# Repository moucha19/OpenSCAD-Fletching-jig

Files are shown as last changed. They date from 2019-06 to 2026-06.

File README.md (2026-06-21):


# OpenSCAD Fletching jig

## Overview
Simple yet effective fletching jig that will adjust to all your needs. Intended to provide new archers with access to 3D printer cheap way to fix broken arrows without a need for expensive off-the-shelf jig. Hopefully, even skilled shooters may find utility in this design.

### Features

+ highly adjustable to fit different arrows and vanes
+ supports any number of vanes (typically 3 or 4)
+ straight, offset and **true** helical fletchings
+ features optional nock alignment
+ no additional tools required for assembly
+ hot swappable arms
+ very compact and light 

## Prerequisites

First you have to download latest version (2019.05 or newer) of [OpenSCAD](http://www.openscad.org/downloads.html). It's free and open source software available for all major desktop platforms. Nothing else is needed for editing and rendering. 

Additional software required will vary depending on your 3D printer.

## How to use

Although I provide several pre-rendered files as an example, it is very likely that you will not like something about them. If some of the parameters do not fit your setup or you simply want to enable some special features mentioned above, you will have to change the relevant parameters in the OpenSCAD customizer and render a new, unique jig yourself. Don't worry though, it is very simple!

1. Download and extract [latest release](https://github.com/moucha19/OpenSCAD-Fletching-jig/releases) of this project somewhere on your PC.
2. Locate [main.scad](./scad/main.scad) and open it in OpenSCAD. 
3. Go to the **Customizer** section:
   - **Windows/Linux**: Click on `Window` in the top menu and select `Customizer`.
   - **macOS**: Click on `View` in the top menu, then select `Customizer`.
4. The Customizer panel will appear on the right side of the OpenSCAD interface.
   - If you don't need to see or edit the code, you can close the editor window on the left to focus solely on the Customizer and 3D view.
5. Adjust the parameters:
   - You will see a list of customizable parameters, such as dimensions and features. See the table below for the detailed description or refer to [parameter reference drawing](./doc/parameter-reference.pdf).
   - Modify these parameters as needed to customize your model.
   - I did all i could to prevent user from inserting invalid values, but there could still be ways to generate completely invalid design - so be reasonable. I'd advise you to change parameters you're sure about first (arrow_diameter, vane_length etc.) and then adjust the rest.
6. **Preview your changes** in real-time. The 3D model will update automatically as you adjust the parameters.
7. Once you're satisfied with the customization, you can render the model (`F6`) and export it to your desired format with `File > Export > ...`.
   - By default, you will get file with every jig part. However, by changing `part_select` parameter, you can isolate individual parts in their correct orientation for 3D printing. This way you can split the jig into multiple files.

### Parameters

Parameter | Description | Thresholds
--- | --- | ---
base_style | choose the base shape | `"polygon"` or `"star"`
lid_style | choose the outer lid shape | `"polygon"` or `"star"`
joint_style | either snap-in ball joints or pin joints | `"ball"` or `"pin"`
arrow_diameter | slightly bigger than the arrow itself (may vary depending on your printer) | 2 < ■
arrow_offset | distance between the bottom of the base and arrow | 0 < ■ < `base_height`
base_height | height of the base | 5 < ■
hinge_width | width of the hinge cutout on the base | 2.2 < ■ < *depends on arrow_diameter*
hinge_thickness | thickness of the hinge extension attached to the bottom of the arm | 1 < ■ < *depends on hinge_width and joint_diameter*
hinge_diameter | diameter of the circular part of the hinge that revolves around a joint | 2 < ■ < `hinge_depth`
hinge_depth | how deep into the base is the hinge cutout | 5 < ■ < `base_height`
joint_diameter | diameter of the joint that connects two halves of the hinge together | 0 < ■ < *depends on joint_style*
arm_gap | gap for the vane foot, so that tension during clamping is distributed evenly and the vane fits in the closed jig | 0 < ■ < 1.5
arm_offset | distance between the top of the base and bottom of the arm | 0 < ■
lid_gap | space between the lid and arms, higher values will produce looser fit (may vary depending on your printer)  | 0 < ■
vane_count | number of vanes, typically 3 or 4 | 2 < ■ 
vane_style | changes shape of the vane | `"straight"` or `"helical"`
vane_length | length of the vane | 0 < ■
vane_width | width of the vane | 0 < ■ < *in the console*
vane_offset | how far from the end of the arrow will the vane be | *in the console* < ■
vane_turn | sets rotation of the fletching in degrees, negative values flip the direction | ■ < *in the console*
nock | choose whether to add a nock alignment guide and if so, how you want to rotate it | `"none"`, `"reference"` or `"alternate"`
nock_width | width of the nock guide, smallest point of the arrow nock | 0 < `arrow_diameter`
nock_height | depth of nock in your arrow, this will be the height of the nock guide | 0 < `(base_height - arrow_offset)`
nock_diameter | if the nock alignment guide is enabled, this value takes precedence over `arrow_diameter` for the base hole when the nocked arrow is wider than bare shaft | 0 < ■



### Thresholds

Like I already mentioned, I've take some precautions to ensure a valid outputs.

First are constrained sliders in customizer. These are set to accommodate even extreme values and should be sufficient for everyone. They're nothing more than recommendations though and even values beyond their range may work just fine. If - for any reason - you'd want to allow values outside of default range, you can do so in `main.scad` by editing lines just like this one:

```openscad
//distance between the bottom of the base and arrow
arrow_offset = 3;//[0:0.1:100] 
```
where comment behind the assignment means *[min:precision:max]*. Go to [customizer documentation](https://customizer.makerbot.com/docs) for more information.

Second are thresholds in the module itself that are actually checking if desired parameters make sense or not. For example, if you have small jig for 6mm arrows, you can't have 10 centimeter wide hinge. So even if you're able to set something like this in the customizer, invalid parameters will be truncated in the module to a closest valid value. If this happens, you'll be informed about it in the console window with similar line:

> hinge_thickness threshold (max = 5.25) reached!

List of some thresholds is in the table above. Some extreme values may still produce invalid results. That could either be because fixing it is more trouble than it's worth or because calculation of thresholds is impossible. Or it can simply be an oversight on my part. If you think something can be improved or you discover a bug, raise an issue or submit PR. 

Also, not all parameters are available in the customizer. Some of them do not change and should not have an effect on the validity of the generated output. However, if you did some testing and think some of these default values could be adjusted to generate better results, let me know.

## Printing recommendations

These settings were tested on Prusa MK2S. You might need to adjust them slightly.

Part | Layer height | Infill | Supports | Bed placement
--- | --- | --- | --- | --- 
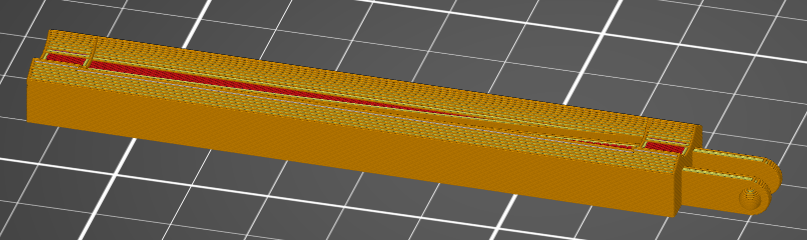
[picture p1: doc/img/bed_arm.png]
Arm | 0.15mm or better | 15% | none / 3mm brim | 
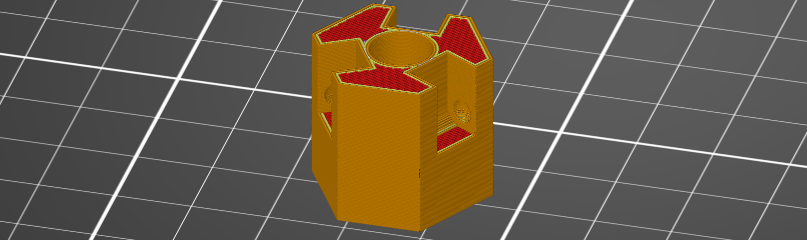
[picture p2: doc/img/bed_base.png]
Base | 0.2mm or better  | 15% | none | 
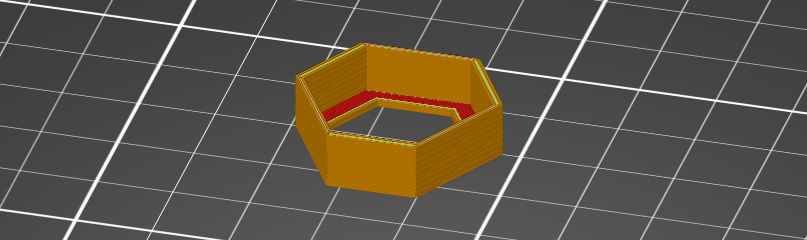
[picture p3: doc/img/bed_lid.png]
Lid | 0.35mm | solid | none | 

***

<br />This work is licensed under a <a rel="license" href="http://creativecommons.org/licenses/by-nc-sa/4.0/">Creative Commons Attribution-NonCommercial-ShareAlike 4.0 International License</a>.

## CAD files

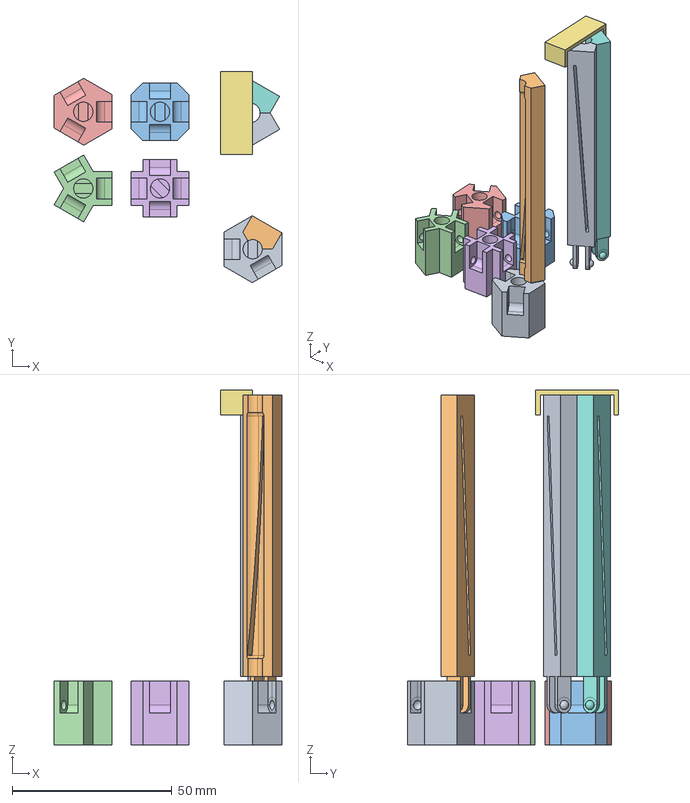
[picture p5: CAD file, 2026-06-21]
doc/parameter-reference.FCStd
71.3 x 66.1 x 111.1 mm
OffsetRotatedBaseBody
OffsetRotatedArmBody
Base4PolygonReferenceSolid
Base3StarAlternateSolid
Base3PolygonReferenceSolid
Base4StarAlternateSolid
LidBody
LidArmBodyLeft
LidArmBodyLeft001

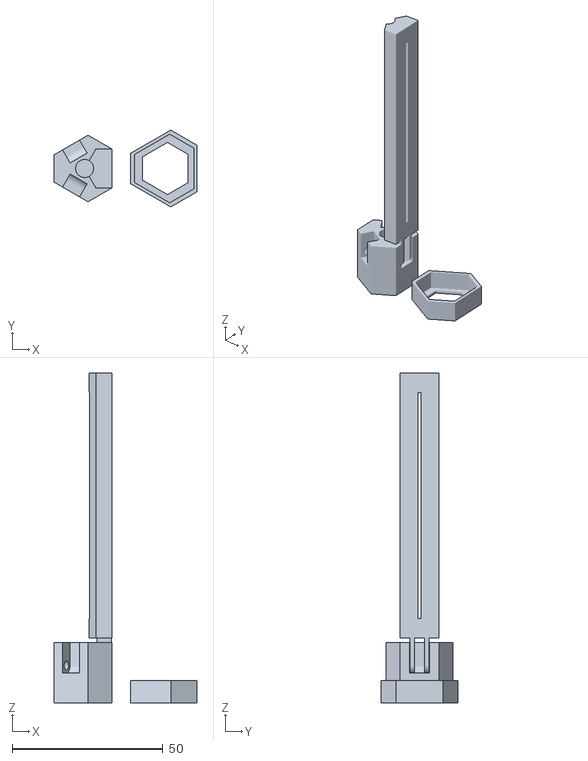
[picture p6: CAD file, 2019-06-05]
stl/jig_6.0_straight.stl
47.4 x 25.5 x 109.5

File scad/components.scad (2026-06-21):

use <MCAD/regular_shapes.scad>

//
//Check out following video made by Eric Buijs
//for more information about bezier curves
//https://www.youtube.com/watch?v=jVPJetq0BZg
//

module bezier (p0, p1, p2, w)
{
    deltat = 0.02;
    cline = [for (t=[0:deltat:1]) pow(1-t,2)*p0+2*(1-t)*t*p1+pow(t,2)*p2];
    last = len(cline) - 1;
    rline = [for(i = [0 : last]) [cline[i].x, cline[i].y - w/2]];
    lline_rev = [for(i = [len(cline) - 1 : -1 : 0]) [cline[i].x, cline[i].y + w/2]];
    //TODO Only works in one orientation
    translate([((p2.x-p0.x)-cline[last].x)/2, 0]) //corrects calculation error 
        polygon(concat(rline, lline_rev));
}

//
//Creates a fillet shape for difference operator
//# r - fillet radius
//# w - width of the filleted edge
//# center - centers on the circle 
//
module fillet(r = 5, w = 5, center=true)
{
    difference()
    {
        translate([r/2,r/2,0]) cube([r,r,w], center=center);
        cylinder(r=r, h=2*w+0.1, center=center);
    }
}

//
//Creates a fillet shape for difference from a cylinder
//# rc - radius of the cylinder
//# r1 - width radius of the fillet
//# r2 - height radius of the fillet 
//# bottom - if true, fillet is generated for the bottom edge, otherwise for the top edge
//

module cylinder_fillet(rc = 5, r1 = 1, r2 = 1, bottom = true)
{
    rotate_extrude(angle = 360, convexity = 2) 
    translate([rc,0,0]) difference()
    {
        square([r1,r2], false);
        translate(bottom ? [0,r2] : [0,0]) 
        ellipse(2*r1, 2*r2);
    }
}

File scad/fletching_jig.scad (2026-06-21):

use <components.scad>

//Functions that create console messages
module error_threshold (value_name, threshold_name, value, threshold)
{
    if (value == threshold) 
    {
        message = str(value_name," threshold (", threshold_name, " = ", threshold, ") reached!");
        if (version()[0] > 2019)
            echo(message);
        else
            echo(str("<font color='red'>", message, "</font>"));
    }
}
module info_threshold (value_name, threshold_name, threshold)
{
    message = str("Current ", threshold_name, " for ", value_name, " is ", threshold);
    if (version()[0] > 2019)
        echo(message);
    else
        echo(str("<font color='blue'>", message, "</font>"));
}

//
//Creates helical vane
//# width - width of the extruded vane profile
//# length - length of the vane
//# height - extrusion height
//# spread - horizontal distance between edges of the vane
//# twist - total twist angle applied across the extrusion
//# direction - sign of the value determines left or right spin (+ left; - right)
//
module helical_vane (width = 1, length = 75, height = 10, spread = 4, twist = 15, direction = 1)
{
    direction = sign(direction);
    length = length;
    rotate([0,90,0])
        linear_extrude(height, center = false, twist = -direction*twist, scale = 1)
            translate([-length/2,0,0])
                bezier([0,-direction*spread],[0.5*length,-direction*spread],[length,direction*spread],width);
}

//
//Creates basic shape of the jig's base
//# style - style of the outline
//# a - length of primary side
//# radius - distance from center to midpoint of primary side (apothem)
//# vane_count - number of vanes
//
module base_outline (style, a, radius, vane_count)
{
    rotation_by = 360/vane_count;
    or = sqrt(pow(a/2, 2) + pow(radius, 2)); //? outside radius
    alpha = atan((a/2)/radius); //? half angle of the hinge side
    beta = (rotation_by - 2*alpha)/2; //? half angle of the secondary side
    b = 2 * or * sin(beta); //? secondary side length
    cross_radius = (or * cos(beta)) - ((b/2)*tan((180-rotation_by)/2));

    points = [for (i=[0:rotation_by:360-rotation_by]) 
        if (style == "star") 
            each 
            [
                [cos(i - alpha)*or, sin(i - alpha)*or],
                [cos(i + alpha)*or, sin(i + alpha)*or],
                [cos(i + alpha + beta)*cross_radius, sin(i + alpha + beta)*cross_radius]
            ]
        else
            each 
            [
                [cos(i - alpha)*or, sin(i - alpha)*or],
                [cos(i + alpha)*or, sin(i + alpha)*or],
            ]
    ];
    polygon(points);
}

//
//Calculates primary and secondary angle of the polygon that encompasses base outline
//
function base_outline_angles(a, radius, vane_count) = [
    2*atan((a/2)/(radius)),
    (360 - vane_count*(2*atan((a/2)/(radius))))/vane_count
];

// Polyhole compensated cylinder (that cut's hole for the arrow into the base) for correct fit 
// https://en.wikibooks.org/wiki/OpenSCAD_User_Manual/undersized_circular_objects
module cylinder_holer(height = 1,radius = 1,fn = 30){
   fudge = 1/cos(180/fn);
   cylinder(h=height,r=radius*fudge,$fn=fn);
}

//
//All three main components of the jig are created here - arm, base and clamping lid
//# arrow_diameter - slightly bigger than the arrow itself (may vary depending on your printer)
//# arrow_offset - distance between the bottom of the base and arrow
//# base_height - height of the base
//# hinge_width - width of the hinge cutout on the base
//# hinge_thickness - thickness of the hinge extension attached to the bottom of the arm
//# hinge_diameter - diameter of the circular part of the hinge that forms a joint
//# hinge_depth - how deep into the base is the hinge cutout
//# joint_diameter - diameter of the sphere that connects two halves of the hinge together 
//# arm_gap - gap for the vane foot, so that tension during clamping is distributed evenly
//# arm_offset - distance between the top of the base and bottom of the arm
//# vane_style - "straight" for a flat vane or "helical" for a true helical twist
//# vane_count - number of vanes
//# vane_length - length of the vane
//# vane_width - width of the vane
//# vane_offset - how far from the end of the arrow will the vane be
//# vane_turn - sets OFFSET/HELICAL fletching angle in degrees
//# nock - "none", "reference" or "alternate"; enables and orients the nock alignment guide
//# nock_width - gap size of the nock
//# nock_height - the height you want the nock guide to be
//# nock_diameter - overrides arrow_diameter for the base hole when set larger than it
//# joint_style - "ball" for snap-in ball joints or "pin" for a hole for an external axle
//# base_style - "polygon" or "star" outline for the base
//# lid_style - "polygon" or "star" outline for the lid
//# lid_gap - clearance between the lid and the arms it slides over
//
module jig (    part_select = 0,
                arrow_diameter = 6,
                arrow_offset = 3,
                base_height = 20,
                hinge_width = 6.5,
                hinge_thickness = 1.5, 
                hinge_diameter = 5,
                hinge_depth = 10,
                joint_diameter = 3,
                arm_gap = 0.5,         
                arm_offset = 1.5,
                vane_style = "straight",
                vane_count = 3,
                vane_length = 75, 
                vane_width = 1.1, 
                vane_offset = 25,
                vane_turn = 0,
                nock = "none",
                nock_width = 3,
                nock_height = 4,
                nock_diameter = 0,
                joint_style = "ball",
                base_style = "polygon",
                lid_style = "polygon",
                lid_gap = 0.25,
                fn = $fn
             ) 
{
    //independent internal variables
    hinge_gap = 0.2;
    hinge_to_arrow_gap = 2;
    min_gap = 0.6;
    flag_showAll = part_select == 0 ? 0 : 1; 

    //input corrections and thresholds
    min_arrow_diameter = 2;
    arrow_diameter = abs(arrow_diameter) >= min_arrow_diameter ? abs(arrow_diameter) : min_arrow_diameter;
    arrow_diameter_base = nock != "none" ? max(arrow_diameter, nock_diameter) : arrow_diameter;

    min_base_height = 5;
    base_height = base_height >= min_base_height ? base_height : min_base_height;

    hinge_depth = abs(hinge_depth) <= base_height 
                    ? (abs(hinge_depth) >= min_base_height ? abs(hinge_depth) : min_base_height)
                    : base_height;
    
    min_hinge_diameter = 2;
    hinge_diameter = abs(hinge_diameter) <= hinge_depth 
                        ? (abs(hinge_diameter) >= min_hinge_diameter ? abs(hinge_diameter) : min_hinge_diameter)
                        : hinge_depth;

    min_hinge_thickness = 1;
    min_hinge_width = 2*min_hinge_thickness + hinge_gap;
    max_hinge_width = (arrow_diameter_base + hinge_to_arrow_gap)*tan(180/vane_count) - 2*min_gap; //length of the side of polygon aroung arrow hole, minus min_gap
    hinge_width     = abs(hinge_width) >= min_hinge_width 
                        ? (abs(hinge_width) <= max_hinge_width ? abs(hinge_width) : max_hinge_width) 
                        : min_hinge_width;

    max_joint_diameter = joint_style == "ball" ? min(hinge_diameter - 2*min_gap, hinge_width - hinge_gap - 2*min_hinge_thickness) : hinge_diameter - 2*min_gap;
    joint_diameter = abs(joint_diameter) <= max_joint_diameter ? abs(joint_diameter) : max_joint_diameter;

    max_hinge_thickness = joint_style == "ball" ? (hinge_width-hinge_gap-joint_diameter)/2 : (hinge_width-hinge_gap)/2;
    hinge_thickness = abs(hinge_thickness) >= min_hinge_thickness
                        ? (abs(hinge_thickness) <= max_hinge_thickness ? abs(hinge_thickness) : max_hinge_thickness) 
                        : min_hinge_thickness;

    arrow_offset = abs(arrow_offset) <= base_height ? abs(arrow_offset) : base_height;

    max_arm_gap = 1.5;
    arm_gap = abs(arm_gap) <= max_arm_gap ? arm_gap : max_arm_gap;

    vane_count = abs(vane_count) >= 2 ? abs(vane_count) : 2;
    vane_length = abs(vane_length);

    arm_offset = abs(arm_offset);

    min_vane_offset = (base_height - arrow_offset) + arm_offset + 4;  
    vane_offset = vane_offset >= min_vane_offset ? vane_offset : min_vane_offset;
    nock_height = abs(nock_height) <= base_height - arrow_offset ? abs(nock_height) : base_height - arrow_offset;
    nock_width = abs(nock_width) <= arrow_diameter ? abs(nock_width) : arrow_diameter;
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

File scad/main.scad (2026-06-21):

use <fletching_jig.scad>

/* [Rendering options] */

// Quality of the generated round elements of the jig. Higher values will generate more polygons, smoother surfaces and slow down the computations.
$fn=30; // [10:10:100]
// Select which part of the jig you want to show
part_select_gui = 0; //[0:All, 1:Base only, 2:Arm only, 3:Lid only]

/* [Hidden] */
part_select_cmd = -1;
part_select = part_select_cmd < 0 ? part_select_gui : part_select_cmd;

/* [Jig style] */
// Style of the base.
base_style = "polygon"; // [ "polygon":Polygon, "star":Star ]
// Style of the lid.
lid_style = "polygon"; // [ "polygon":Polygon, "star":Star ]
// You can either have a snap-in ball joints or a hole for external axle (like bolt or piece of filament).
joint_style = "ball"; // [ "ball":Ball joint, "pin":Pin joint ]

/* [Jig dimensions] */

// Your arrow diameter. This number should be slightly bigger than the arrow itself to take into account the precision of your printer.
arrow_diameter = 6;//[2:0.1:30]

// Distance between the bottom of the base and arrow. A smaller offset will restrict the vane offset as the arrow will be deeper into the base.
arrow_offset = 3;//[0:0.1:100]

// Height of the base.
base_height = 20;//[0:0.1:100]

// Width of the hinge cutout on the base. The maximum value will depend on the arrow diameter.
hinge_width = 6.5;//[0:0.1:30]

// Thickness of the hinge extension attached to the bottom of the arm. The maximum value depends on the hinge width. A larger hinge will be harder to assemble.
hinge_thickness = 1.5;

// Diameter of the hinge's circular part. A larger value will produce larger arms. The maximum value is the hinge depth.
hinge_diameter = 5.1;

// How deep into base is the hinge cutout. The maximum value is the base height. Smaller values will be harder to assemble as the arms will be less flexible.
hinge_depth = 10.1;

// Diameter of the joint that connects two halves of the hinge together. Maximum depends on both the hinge diameter and the joint style.
joint_diameter = 3.1;

// Gap for the vane foot in the arm so that the tension is distributed evenly on the vanes during clamping. This value will depend on your vanes. A value too small will clamp unevenly, a value too large will not clamp the vane.
arm_gap = 0.5;

// Distance between the top of the base and bottom of the arm.
arm_offset = 1.5;//[0.1:0.1:2]

// Gap between the lid and the arms it slides over. A larger value makes the lid easier to slide on and off, a smaller value makes for a tighter fit.
lid_gap = 0.25;//[0:0.01:1]

/* [Fletching] */

//Select vane style
vane_style = "straight";//["straight":Straight, "helical":Helical]

// Number of vanes.
vane_count = 3;//[2:1:6]

// Length of the vane.
vane_length = 72.1;//[0:0.1:200]

// Width of the vane.
vane_width = 1.1;//[0:0.1:10]

// How far from the end of arrow will the vane be. The minimal value will depend on the arrow offset, the base height and the arm offset.
vane_offset = 25.1;//[0:0.1:200]

// Offset of the fletching in degrees. The maximum value will depend on the arrow radius, the fletching width, the fletching length as well as the arm gap.
vane_turn = 0;//[-30:0.1:30]

/* [Nock alignment] */

// Alignment guide for nocked arrows. You can either choose to align nock to reference vane, or rotate nock to alternate symmetric orientation based on vane count.
nock = "none"; // [ "none":Disabled, "reference" : Reference vane alignment, "alternate": Alternate alignment]

// Width of the nock (measure smallest point)
nock_width = 3;//[0:0.1:5]

// Depth of the nock groove (height of the nock guide)
nock_height = 4;//[0:0.1:20]

// Nock diameter. If it is larger than the arrow diameter, it will be used for the hole in the base, otherwise it has no effect.
nock_diameter = 0;//[2:0.1:30]

// Verbose info for command line rendering
if (part_select_cmd != -1)
{
    echo(str("Selected part = ", part_select));
    echo(str("Arrow diameter = ", arrow_diameter));
    echo(str("Vane style = ", vane_style == "helical" ? "Helical" : "Straight"));
    echo(str("Vane turn = ", vane_turn));
}

jig (
        part_select,
        arrow_diameter,
        arrow_offset,
        base_height,
        hinge_width,
        hinge_thickness,
        hinge_diameter,
        hinge_depth,
        joint_diameter,
        arm_gap,
        arm_offset,
        vane_style,
        vane_count,
        vane_length,
        vane_width,
        vane_offset,
        vane_turn,
        nock,
        nock_width,
        nock_height,
        nock_diameter,
        joint_style,
        base_style,
        lid_style,
        lid_gap
    );

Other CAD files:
scad/quadratic_bezier.scad

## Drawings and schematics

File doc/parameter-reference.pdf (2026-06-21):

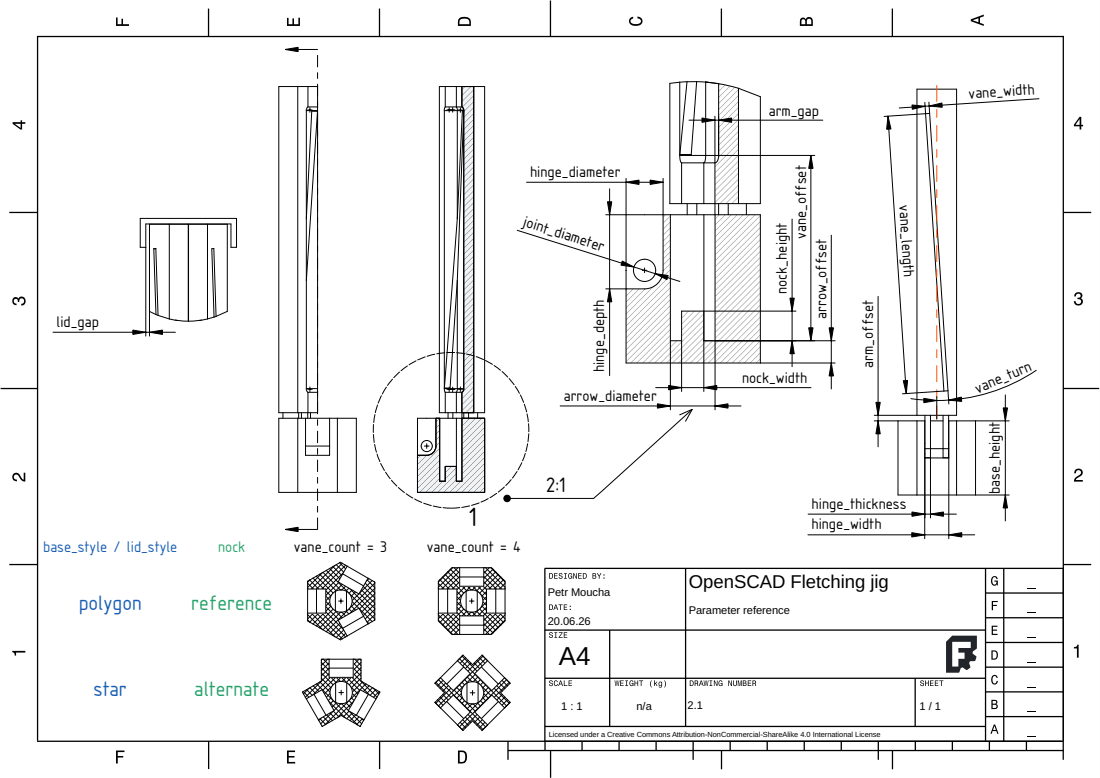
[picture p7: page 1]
base_style / lid_style; vane_count = 3; vane_count = 4

Petr Moucha 20.06.26 | OpenSCAD Fletching jig Parameter reference

Licensed under a Creative Commons Attribution-NonCommercial-ShareAlike 4.0 International License

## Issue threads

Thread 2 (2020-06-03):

Variable Helical formula

condac, 2020-06-03:
I do not have a ton of archery experience so I am not sure exactly how people want a helical to look like but for me it does not look right.
I was trying to do helical with a bit lower angles. And the angle where the fletching is contacting the shaft is not 90 deg all ower the length of the fletching. I thought the basic behind a helical was that the angle was 90 deg ower the entire lenght.

Looking at the code the twist is static `twist = -direction*15` this was maybe supposed to be dynamic?

Here is an image of the helical preset but the angle set to 1 deg. It is straight on the shaft side but on the fletching side it is at an extreme twist.
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

moucha19, 2021-04-17:
Hello, I'm so sorry that I'm replying to this so late, but i haven't received any notification and I don't really check GitHub regularly because i hoped i would receive an email or something.

Anyways, you are absolutely correct, the twist is static and i chose a value that seemed reasonable to most of the helical jigs i printed. If I remember correctly, I was trying to fix this but it was really difficult to adjust this twist properly for different values. I could've probably hardcode different values for different ranges, and i will try to do so whenever i have time.

However, if you have any idea how to calculate the twist value exactly, I'm open to suggestions!

condac, 2021-04-18:
I also had the same problem with notifications, default settings do not notify you, so no problem.

This was very long time ago so I do not remember what i did. But I have a branch where I have done something you can test. It adds a screw type to helical options.I have created a pull request for you to look and see if you want it.

moucha19, 2021-04-18:
So I fixed the twist issue and it should now adjust to helical_adjust parameter automatically. However, i tried to make your linear implementation work, but it didn't play nicely with some parameters, especially direction and it seemed inconsistent. I tried to extrude straight line instead of bezier curve to emulate your idea, but for some reason, it never rendered correctly even though in preview it looked okay. I tried some fixes, but since regular helical should be working fine now, I removed it for now so that i can release working revision ASAP.
Let me know if you're going to test it and if it's going to be okay! Thank you!

Closed 2021-04-18.

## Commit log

2019-06-02 v1.0 basic version with straight fletching support
    [fletching_jig.scad, jig_6_straight.stl]
2019-06-02 v1.1 offset fletching supported
    [fletching_jig.scad]
2019-06-02 basic helical curve created
    [fletching_jig.scad]
2019-06-02 helical spread now depends on arrow diameter
    [fletching_jig.scad]
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2019-06-02 helical vane is aligned properly, fixed bezier curve
    [fletching_jig.scad]
2019-06-02 added code for bezier curve
    [quadratic_bezier.scad]
2019-06-02 fixed deltat value
    [quadratic_bezier.scad]
2019-06-03 added helical adjust and radius variables
    [fletching_jig.scad]
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2019-06-04 fixed helical_direction not working properly for right spin
    [fletching_jig.scad]
2019-06-05 arm_height no longer fixed value, lid height adjusted
    [fletching_jig.scad]
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2019-06-05 distributed hinge module into separate file, created main
    [fletching_jig.scad, hinge.scad, main.scad]
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2019-06-05 hinge_gap now applies to hinge_pin, minor changes
    [fletching_jig.scad, main.scad]
2019-06-06 hinge height fixed
    [fletching_jig.scad]
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2019-06-06 hinge pins are now bigger
    [hinge.scad]
2019-06-06 hinge_adjust calculation changed x position of helical vane now adapts to helical_adjust
    [fletching_jig.scad, jig_8.0_helical-right-0.5.stl, jig_8.0_helical-right-2.2.stl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]
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2019-06-06 helical_adjust is now 2*spread
    [fletching_jig.scad, main.scad]
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2019-06-11 added support for customizer
    [fletching_jig.scad, main.scad]
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2019-06-11 changed default render quality
    [main.scad]
2019-06-15 hinge_diameter now affects base_diameter
    [fletching_jig.scad]
2019-06-17 updated base_mold and added some input corrections
    [fletching_jig.scad]
2019-06-18 smoothened arm gap edges
    [fletching_jig.scad]
2019-06-18 added minimal vane_offset treshold
    [fletching_jig.scad]
2019-06-19 added more input corrections, removed debug output
    [fletching_jig.scad]
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2019-06-27 updated error format
    [fletching_jig.scad, main.scad]
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2019-06-30 part_select now places components properly
    [fletching_jig.scad]
2019-06-30 hinge_thickness now adjustable by user
    [fletching_jig.scad, hinge.scad, main.scad]
2019-07-01 finished most of input checks
    [fletching_jig.scad]
2019-07-01 input correction changed to prefer reducing hinge_pin instead of hinge_thickness
    [fletching_jig.scad]
2019-07-02 min_hinge_width fix
    [fletching_jig.scad]
2019-07-02 minor improvements, updated customizer tresholds
    [fletching_jig.scad, main.scad]
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2019-10-13 Improve the help texts on the Customizer pane
    [fletching_jig.scad, main.scad]
2020-06-08 Screw helical with linear twist
    [fletching_jig.scad, main.scad]
2020-06-08 Polyhole fix for shaft in base
    [fletching_jig.scad, main.scad]
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2021-04-18 fixed twist angle based on helical adjust
    [fletching_jig.scad, main.scad]
2021-04-18 added script to render all presets
    [main.scad]
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2023-10-02 Add nock for alignment wooden arrows
    [fletching_jig.scad, main.scad, rounded_cube.scad]
2023-10-15 Removed roundedcube module, simplified nock module
    [components.scad, fletching_jig.scad, rounded_cube.scad]
2023-10-15 Added treshold check for nock dimensions.
    [fletching_jig.scad, main.scad]
2023-10-15 Fixed incorrect nock length.
    [fletching_jig.scad]
2023-11-04 Fixed issue when nock would be displayed without the base selected.
    [fletching_jig.scad]
2023-11-05 Moved images, added script to merge single scad.
    [drawing.FCStd, fletching_jig.scad]
2023-11-08 Reimplemented vane foot fillet without `minkowski()`.
    [components.scad, fletching_jig.scad]
2023-11-08 Implemented helical vane without `hull()`. Rounded vane foot cutout below the vane slot.
    [components.scad, fletching_jig.scad]
2023-11-19 JM: hinge_holes not spheres
    [fletching_jig.scad, hinge.scad, main.scad]
2023-11-19 JM: holed and tricorn style base with 6.1mm preset example
    [fletching_jig.scad, hinge.scad, main.scad]
2023-11-19 JM: option to show base and lid only
    [fletching_jig.scad, main.scad]
2023-11-19 JM: renaming hinge_pin to hinge_pin_diameter
    [fletching_jig.scad, hinge.scad, main.scad]
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2023-11-19 JM: renamed parameters - now hinge_pin, base_style and hinge_style
    [fletching_jig.scad, hinge.scad, main.scad]
2023-11-19 JM: reverting changes to existing presets, added new params
    [main.scad]
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2023-11-19 Fixed max_hinge_pin error in log.
    [fletching_jig.scad]
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2024-08-16 Fixed uneven wall thickness of the lid
    [fletching_jig.scad]
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2024-08-16 Nested hinge module into fletching_jig module, added style parameters
    [fletching_jig.scad, hinge.scad, main.scad]
2024-08-16 Simplified hinge, improved arm_width calculation, implemented base/lid style selection
    [fletching_jig.scad]
2024-08-16 Removed dedicated nock_insert module and arbitrary nock fillet
    [fletching_jig.scad]
2024-08-16 Added `nock_diameter` parameter to support arrows with overnocks
    [fletching_jig.scad, main.scad]
2024-08-16 Added the ability to choose nock orientation for 4-vane fletching
    [fletching_jig.scad, main.scad]
2024-08-17 Parameter value bug fixes
    [fletching_jig.scad]
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2024-08-17 Removed HTML output decoration for latest OpenSCAD versions, where this feature was unfortunately removed
    [fletching_jig.scad]
2024-08-17 Simplified parameters for the helical fletching. Fixed incorrect length of the helical cutout.
    [components.scad, fletching_jig.scad, main.scad]
2024-08-17 Separated nock settings, ignore nock diameter if nock is disabled. Changed default lid style.
    [fletching_jig.scad, main.scad]
2024-08-18 Added updated parameter reference drawing along with source FreeCAD document to allow contributors to easily update the drawing if necessary
    [drawing.FCStd, parameter-reference.FCStd]
2024-08-18 Renamed `hinge_pin` to `joint_diameter` and `hinge_style` to `joint_style`
    [fletching_jig.scad, main.scad, parameter-reference.FCStd]
2024-08-18 Improved `hinge_thickness` parameter check and fixed `vane_turn` calculation
    [fletching_jig.scad]
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2024-08-18 Calculation of maximum `joint_diameter` now follows different rules for pin joint
    [fletching_jig.scad]
2024-08-18 Add option to specify diameter of the nock
    [fletching_jig.scad, main.scad]
2024-08-18 Updated presets and improved render script. Removed stls from repository
    [6.0_arm_helical-right-3.5.stl, 6.0_arm_straight.stl, 6.0_lid.stl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]
2024-08-18 Fixed typos and misspellings
    [fletching_jig.scad]
2024-08-18 Fixed misalignment of hinge and arm due to `arm_gap`
    [fletching_jig.scad]
2026-06-20 Improve nock alignment configuration to properly support 3 vane setup for compound bow
    [fletching_jig.scad, main.scad]
2026-06-20 Update parameter reference drawing to display nock style effect based on vane count
    [parameter-reference.FCStd]
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
